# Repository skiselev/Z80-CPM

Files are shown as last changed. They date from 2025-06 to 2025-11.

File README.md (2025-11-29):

# Z80-CPM
RCBus Z80 CPU, 512 KiB SRAM, and 512 KiB Flash ROM module for RCBus systems designed using discrete logic

## Table of Content
* [Overview](#overview)
  * [Specifications](#specifications)
* [Assembly Instructions](#assembly-instructions)
* [Hardware Documentation](#hardware-documentation)
  * [Schematic and PCB Layout](#schematic-and-pcb-layout)
  * [Input/Output Ports](#inputoutput-ports)
  * [Connectors](#connectors)
  * [Bill of Materials](#bill-of-materials)
* [Release Notes](#release-notes)
  * [Changes](#changes)
  * [Known Issues](#known-issues)
* [Red Tape](#red-tape)
  * [Licensing](#licensing)
  * [Trademarks](#trademarks)

## Overview
Z80-CPM is an RCBus and RC2014* compatible module, designed to run [RomWBW](https://github.com/wwarthen/RomWBW) firmware including CP/M, ZSDOS, and various applications under these OSes. Z80-CPM combines functionality of the following RC2014* modules on a single module, thus saving space on the backplane:
* Z80 CPU Module
* 512k ROM 512k RAM Module - Simplified version, compatible with RomWBW firmware
* Clock and Reset Module

Minimal CP/M computer system can be built using Z80-CPM module, a backplane, and a serial port module, for example Steve Cousins' [SC716](https://smallcomputercentral.com/sc716-rcbus-z80-sio-2-serial-module/) or [SC725](https://smallcomputercentral.com/sc725-rcbus-serial-and-timer-module/) Z80 SIO modules, or MC68B50 ACIA. A Compact Flash module can be added for additional storage. For a compact system, a 3-slot [SC723](https://smallcomputercentral.com/sc723-rcbus-backplane-3/) can be used.

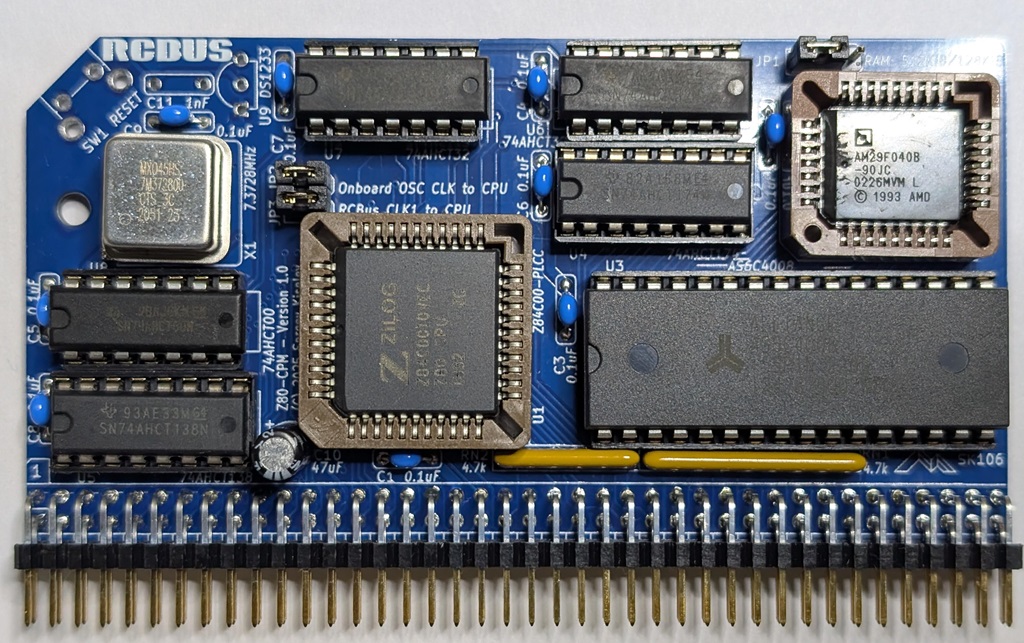
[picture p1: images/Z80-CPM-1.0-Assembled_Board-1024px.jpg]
Z80-CPM Assembled Board


### Specifications
* Processor: Zilog* Z80 CPU (CMOS version - Z84C00)
* Memory: 512 KiB SRAM, 512 KiB Flash ROM, RomWBW compatible memory pager
* Bus: RCBus, RC2014* compatible
* Microprocessor Supervisor for system reset generation

## Assembly Instructions

Please refer to [Assembly Instructions](Assembly_Instructions.md) document

## Hardware Documentation

### Schematic and PCB Layout

* [Schematic - Version 1.0](KiCad/Z80-CPM-Schematic-1.0.pdf)
* [PCB Layout - Version 1.1](KiCad/Z80-CPM-Board-1.1.pdf)
* [PCB Layout - Version 1.0](KiCad/Z80-CPM-Board-1.0.pdf)

### Memory Configuration Input/Output Ports
Z80-CPM supports up to 512 KiB of RAM and up to 512 KiB of Flash ROM. It has a simple memory bank switching mechanism with two 32 KiB memory banks, inspired by Steve Cousin's [SC602](https://smallcomputercentral.com/rcbus/sc600-series/sc602-rcbus-z80-memory-module/) Memory Module. This memory bank mechanism provides minimal required functionality for the RomWBW RCZ80_std.rom image to be used without any modifications.
The upper 32 KiB bank is always mapped to the top 32 KiB of the physical RAM. The lower 32 KiB bank can be mapped to any 32 KiB size page in the physical memory. The memory page is selected by writting either 0x78 or 0x79 I/O ports, that are mapped to the same page select register.

#### 0x78 or 0x79 - Memory Page Select Register (Write-only)

Port       | Bit # | Function                               | Value
-----------|-------|----------------------------------------|-----------------------
0x78, 0x79 | 0     | Not implemented                        | Can be set to either 0 or 1
0x78, 0x79 | 5-1   | Page number for bank #0 0x0000-0xr7FFF | 0-31 - Page number
0x78, 0x79 | 7-6   | Not implemented                        | Should be set to 0

* Notes:
  * The register is reset to '0' on power-on or reset, which maps the lower 32 KiB of the Flash ROM to bank #0.
  * Bit 5 selects between the Flash ROM (bit 5 = 0) and the RAM (bit 5 = 1).

### Jumpers Settings

#### JP1 - RAM Size Configuration

Jumper Position | Description
----------------|------------
1-2             | 512 KiB SRAM
2-3             | 128 KiB SRAM

#### JP2 - Connect on-board oscillator clock to the CPU

Jumper Position | Description
----------------|------------
**Closed**      | X1 oscillator is connected to the CPU
Open            | X1 oscillator is not connected to the CPU

#### JP3 - Connect the RCBus CLK1 signal to the CPU

Jumper Position | Description
----------------|------------
**Closed**      | CLK1 signal is connected to the CPU
Open            | CLK1 signal is not connected to the CPU

#### JP2 and JP3 Configuration Notes

The module supports the following options for the CPU clock:
1. **Default**: CPU uses the clock frequency generated by the X1 oscillator, and the X1 clock frequency is output to CLK1 signal on RCBus. Install both JP2 and JP3 for this option.
2. CPU uses the clock frequency provided by another module on RCBus. Install only JP3 for this option.
3. CPU uses the clock frequency generated by the X1 oscillator, while other modules use different CLK1 signal. This might be useful, for example, when running the CPU on a frequency other than 7.3728 MHz. Install only JP2 for this option.

### Connectors

#### J1 - RC2014* Bus
Pin | Signal Name | Description                             | Pin | Signal Name | Description
--- | ----------- | --------------------------------------- | --- | ----------- | -----------
1   | A15         | Address A15; Output                    | 41  | p41         | Reserved; Not connected
2   | A14         | Address A14; Output                     | 42  | /BAI        | Bus Acknowledge In; Not connected
3   | A13         | Address A13; Output                     | 43  | /BAO        | Bus Acknowledge Out; Not connected
4   | A12         | Address A12; Output                     | 44  | p44         | Reserved; Not connected
5   | A11         | Address A11; Output                     | 45  | p45         | Reserved; Not connected
6   | A10         | Address A10; Output                     | 46  | p46         | Reserved; Not connected
7   | A9          | Address A9; Output                      | 47  | p47         | Reserved; Not connected
8   | A8          | Address A8; Output                      | 48  | p48         | Reserved; Not connected
9   | A7          | Address A7; Output                      | 49  | A23         | Address A23; Not connected
10  | A6          | Address A6; Output                      | 50  | A22         | Address A22; Not connected
11  | A5          | Address A5; Output                      | 51  | A21         | Address A21; Not connected
12  | A4          | Address A4; Output                      | 52  | A20         | Address A20; Not connected
13  | A3          | Address A3; Output                      | 53  | A19         | Address A19; Output
14  | A2          | Address A2; Output                      | 54  | A18         | Address A18; Output
15  | A1          | Address A1; Output                      | 55  | A17         | Address A17; Output
16  | A0          | Address A0; Output                      | 56  | A16         | Address A16; Output
17  | GND         | Ground                                  | 57  | GND         | Ground
18  | VCC         | Power Supply - +5V                      | 58  | VCC         | Power Supply - +5V
19  | /M1         | Machine Cycle One; Output               | 59  | /RFSH       | DRAM refresh; Output
20  | /RESET      | Reset; Output                           | 60  | PAGE         | Page ROM/RAM input; Not connected
21  | CLK1        | CPU Clock; Output                       | 61  | CLK2        | UART Clock; Not connected
22  | /INT        | Interrupt; Input                        | 62  | /BUSACK     | DMA Bus Acknowledge; Output
23  | /MREQ       | Memory Request; Output                  | 63  | /HALT       | Halt; Output
24  | /WR         | Write Request; Output                   | 64  | /BUSREQ     | DMA Bus Request; Input
25  | /RD         | Read Request; Output                    | 65  | /WAIT       | Wait; Input
26  | /IORQ       | Input/Output Request; Output            | 66  | /NMI        | Non-maskable Interrupt; Input
27  | D0          | Data D0; Input/Output                   | 67  | D8          | Data D8; Input/Output; Not connected
28  | D1          | Data D1; Input/Output                   | 68  | D9          | Data D9; Input/Output; Not connected
29  | D2          | Data D2; Input/Output                   | 69  | D10         | Data D10; Input/Output; Not connected
30  | D3          | Data D3; Input/Output                   | 70  | D11         | Data D11; Input/Output; Not connected
31  | D4          | Data D4; Input/Output                   | 71  | D12         | Data D12; Input/Output; Not connected
32  | D5          | Data D5; Input/Output                   | 72  | D13         | Data D13; Input/Output; Not connected
33  | D6          | Data D6; Input/Output                   | 73  | D14         | Data D14; Input/Output; Not connected
34  | D7          | Data D7; Input/Output                   | 74  | D15         | Data D15; Input/Output; Not connected
35  | TX          | Channel 1, Transmit Data; Not Connected | 75  | TX2         | Channel 2, Transmit Data; Not Connected
36  | RX          | Channel 1, Receive Data; Not Connected  | 76  | RX2         | Channel 2, Receive Data; Not Connected
37  | /IRQ1       | Interrupt Request 1; Not connected      | 77  | /IRQ2       | Interrupt Request 2; Not connected
38  | IEI         | Interrupt Enable In; Not connected      | 78  | p78         | Reserved; Not connected
39  | IEO         | Interrupt Enable Out; Not connected     | 79  | p79         | Reserved; Not connected
40  | USER4       | User Pin 4; Not connected               | 80  | USER8       | User Pin 8; Not connected

### Bill of Materials

#### Version 1.0

Mouser projects - All components except of the PCB and the CPU:
* [Z80-CPM project](https://www.mouser.com/Tools/Project/Share?AccessID=cf00dde769)
  * Note that optional CPU supervisor parts: U9 DS1233 CPU supervisor, C11 1 nF capacitor, and SW1 tactile switch are included in this project.

Z80-CPM project on Tindie:
* [Complete kit](https://www.tindie.com/products/weird/z80-cpm-rcbus-module-kit/).
* [Z80-CPU PCB](https://www.tindie.com/products/weird/z80-cpm-rcbus-module-pcb/).

Component type     | Reference | Description                                 | Quantity | Possible sources and notes 
------------------ | --------- | ------------------------------------------- | -------- | --------------------------
PCB                |           | Z80-CPM PCB - Version 1.0                   | 1        | Buy from my Tindie store: [Complete kit](https://www.tindie.com/products/weird/z80-cpm-rcbus-module-kit/); [Z80-CPM PCB](https://www.tindie.com/products/weird/z80-cpm-rcbus-module-pcb/), or order from a PCB manufacturer of your choice using provided Gerber or KiCad files
Integrated Circuit | U1        | Z84C00xxVEG - Z80 CPU, CMOS, 44 pin PLCC    | 1        | Mouser [692-Z84C0010VEG](https://www.mouser.com/ProductDetail/692-Z84C0010VEG)
Integrated Circuit | U2        | SST39SF040 - 512 KiB Flash ROM, 32 pin PLCC | 1        | Mouser [804-39SF0407CNHE](https://www.mouser.com/ProductDetail/804-39SF0407CNHE)
Integrated Circuit | U3        | AS6C4008 - 512 KiB SRAM, 32 pin DIP         | 1        | Mouser [913-AS6C4008-55PCN](https://www.mouser.com/ProductDetail/913-AS6C4008-55PCN)
Integrated Circuit | U4        | 74AHCT174 - Hex D-Type Flip Flop, 16 pin DIP | 1       | Mouser [595-SN74AHCT174N](https://www.mouser.com/ProductDetail/595-SN74AHCT174N)
Integrated Circuit | U5        | 74HCT138 - 3-to-8 Decoder, 16 pin DIP       | 1        | Mouser [595-CD74HCT138E](https://www.mouser.com/ProductDetail/595-CD74HCT138E)
Integrated Circuit | U6, U7    | 74AHCT32 - Quad 2-Input OR Gate, 14 pin DIP | 2        | Mouser [595-SN74AHCT32N](https://www.mouser.com/ProductDetail/595-SN74AHCT32N)
Integrated Circuit | U8        | 74AHCT00 - Quad 2-Input NAND Gate, 14 pin DIP | 1      | Mouser [595-SN74AHCT00N](https://www.mouser.com/ProductDetail/595-SN74AHCT00N)
Integrated Circuit | U9        | DS1233-5 - CPU Supervisor, 5V, TO-92-3      | 1        | Mouser [700-DS1233-5](https://www.mouser.com/ProductDetail/700-DS1233-5). Note U9 is an optional on-board CPU supervisor.
Oscillator         | X1        | 7.3728 MHz, CMOS oscillator, half can       | 1        | Mouser [774-MXO45HS-3C-7.3](https://www.mouser.com/ProductDetail/774-MXO45HS-3C-7.3) or [520-2200B-073](https://www.mouser.com/ProductDetail/520-2200B-073)
Pin Header         | J1        | 40x2 pin header, 2.54 mm pitch, right angle | 1        | Mouser [737-PH2RA-80-UA](https://www.mouser.com/ProductDetail/737-PH2RA-80-UA), [517-5121TG](https://www.mouser.com/ProductDetail/517-5121TG)
Pin Header         | JP1       | 3x1 pin header, 2.54 mm pitch, vertical     | 1        | Mouser [649-68000-203HLF](https://www.mouser.com/ProductDetail/649-68000-203HLF).
Pin Header         | JP2, JP3  | 2x2 pin header, 2.54 mm pitch, vertical     | 1        | Mouser [649-67996-104HLF](https://www.mouser.com/ProductDetail/649-67996-104HLF).
Jumper             | JP1 - JP3 | Shunt, 2 pin 2.54 mm pitch                  | 3        | Mouser [806-SX1100-B](https://www.mouser.com/ProductDetail/806-SX1100-B).
Tactile switch     | SW1       | Tactile switch, 6 mm, right angle           | 1        | Mouser [653-B3F-3152](https://www.mouser.com/ProductDetail/653-B3F-3152). SW1 is an optional reset switch.
Capacitor          | C1 - C9   | 0.1 uF, 50V, MLCC, 5 mm pitch               | 9        | Mouser [594-K104K15X7RF53H5](https://www.mouser.com/ProductDetail/594-K104K15X7RF53H5).
Capacitor          | C10        | 47 uF, 25V, electrolytic, 5 x 11 mm, 2 mm pitch | 1    | Mouser [667-EEU-FR1E470](https://www.mouser.com/ProductDetail/667-EEU-FR1E470)
Capacitor          | C11       | 1 nF, 50V, MLCC, 5 mm pitch                 | 1        | Mouser [594-K102K15X7RF5TH5](https://www.mouser.com/ProductDetail/594-K102K15X7RF5TH5). Note: C11 is optional, required if U9 installed and manual reset functionality is desired.
Resistor Array     | RN1       | 4.7 kohm, bussed, 9 pin SIP                 | 1        | Mouser [652-4609X-1LF-4.7K](https://www.mouser.com/ProductDetail/652-4609X-1LF-4.7K) or [652-4609X-AP1-472LF](https://www.mouser.com/ProductDetail/652-4609X-AP1-472LF)
Resistor Array     | RN2       | 4.7 kohm, bussed, 6 pin SIP                 | 1        | Mouser [652-4606X-1LF-4.7K](https://www.mouser.com/ProductDetail/652-4606X-1LF-4.7K) or [652-4606X-AP1-472LF](https://www.mouser.com/ProductDetail/652-4606X-AP1-472LF)
IC Socket          | U1        | 44 pin PLCC, through hole                   | 1        | Mouser [737-PLCC-44-AT](https://www.mouser.com/ProductDetail/737-PLCC-44-AT), [517-8444-11B1-RK-TP](https://www.mouser.com/ProductDetail/517-8444-11B1-RK-TP)
IC Socket          | U2        | 32 pin PLCC, through hole                   | 1        | Mouser [737-PLCC-32-AT](https://www.mouser.com/ProductDetail/737-PLCC-32-AT), [517-8432-11B1-RK-TP](https://www.mouser.com/ProductDetail/517-8432-11B1-RK-TP)
IC Socket          | U3        | 32 pin DIP                                  | 1        | Mouser [737-ICS-632-T](https://www.mouser.com/ProductDetail/737-ICS-632-T), [517-4832-6000-CP](https://www.mouser.com/ProductDetail/517-4832-6000-CP)
IC Socket          | U4, U5    | 16 pin DIP                                  | 2        | Mouser [737-ICS-316-T](https://www.mouser.com/ProductDetail/737-ICS-316-T), [517-4816-3000-CP](https://www.mouser.com/ProductDetail/517-4816-3000-CP).
IC Socket          | U6 - U8   | 14 pin DIP                                  | 3        | Mouser [737-ICS-314-T](https://www.mouser.com/ProductDetail/737-ICS-314-T), [517-4816-3000-CP](https://www.mouser.com/ProductDetail/517-4816-3000-CP).
Oscillator Socket  | X1        | 4 pin DIP, Half Can                         | 1        | Mouser [535-1108800](https://www.mouser.com/ProductDetail/535-1108800)

## Release Notes

### Changes

* Version 1.1
  * Fix cosmetic issues:
    * Swap C5 with C8 and C4 with C6.
    * Modify C10 footpring to clearly show negative terminal.

* Version 1.0
  * Initial version.

### Known Issues

* Version 1.0
  * Cosmetic issues:
    * C5 and C8, and C6 and C4 should be swapped.
    * C10 should have more clear marking for the negative terminal.

## Red Tape

### Licensing

Z80-CPM is an open source hardware project. The hardware design itself, including schematic and PCB layout design files are licensed under the strongly-reciprocal variant of [CERN Open Hardware Licence version 2](license-cern_ohl_s_v2.txt). Documentation, including this file, is licensed under the [Creative Commons Attribution-ShareAlike 4.0 International License](license-cc-by-sa-4.0.txt).

CERN-OHL-2.0-S, GPL-3.0, CC-BY-SA-4.0

### Trademarks

* "RC2014" is a registered trademark of RFC2795 Ltd.
* Other names and brands may be claimed as the property of others.

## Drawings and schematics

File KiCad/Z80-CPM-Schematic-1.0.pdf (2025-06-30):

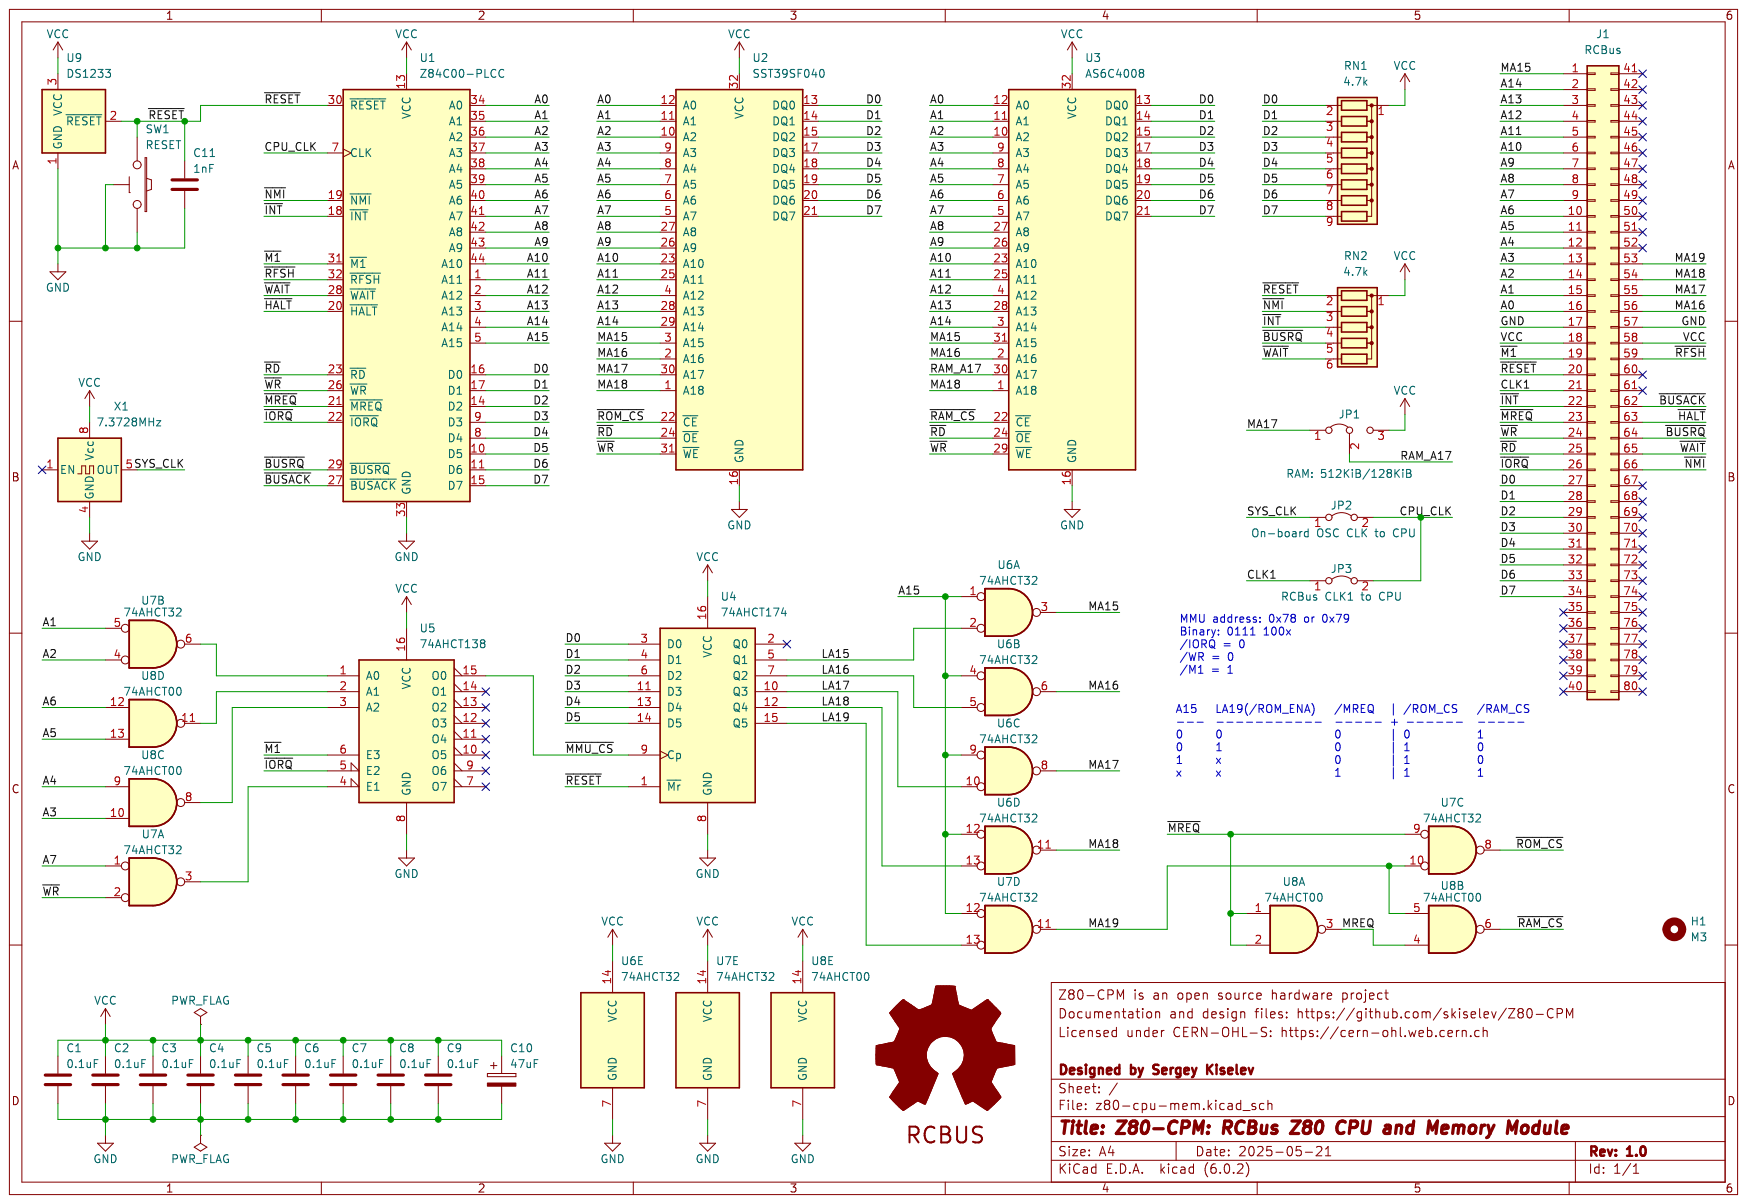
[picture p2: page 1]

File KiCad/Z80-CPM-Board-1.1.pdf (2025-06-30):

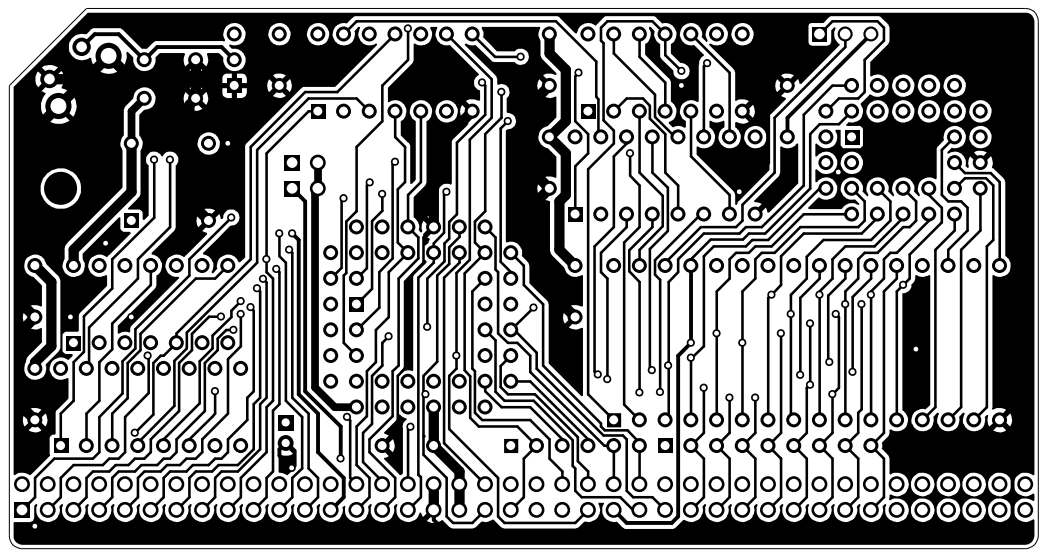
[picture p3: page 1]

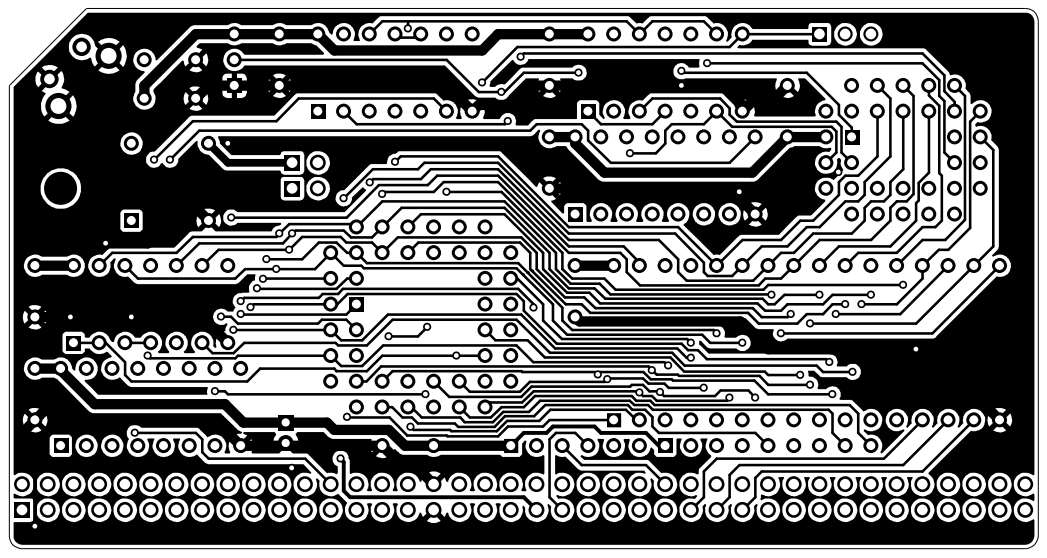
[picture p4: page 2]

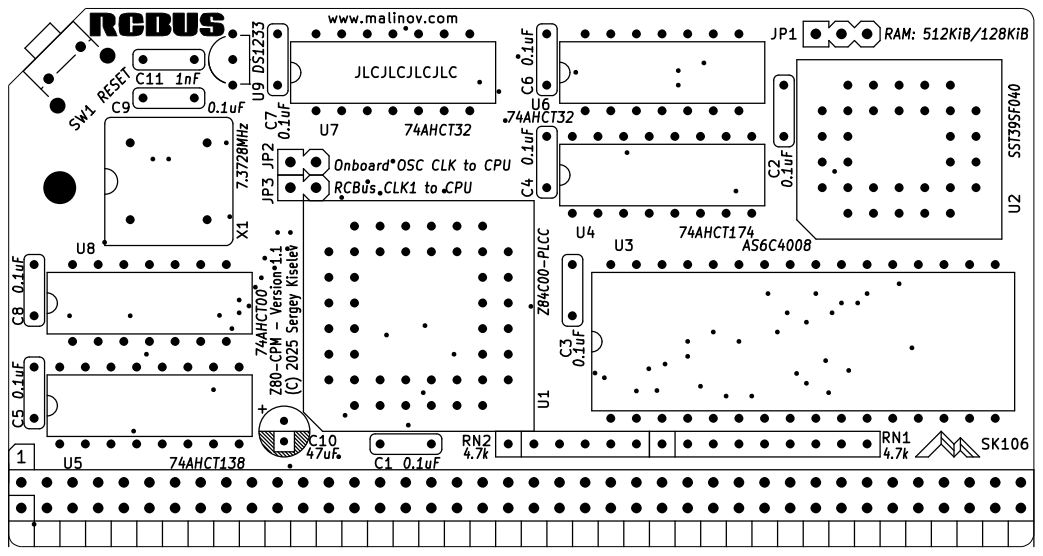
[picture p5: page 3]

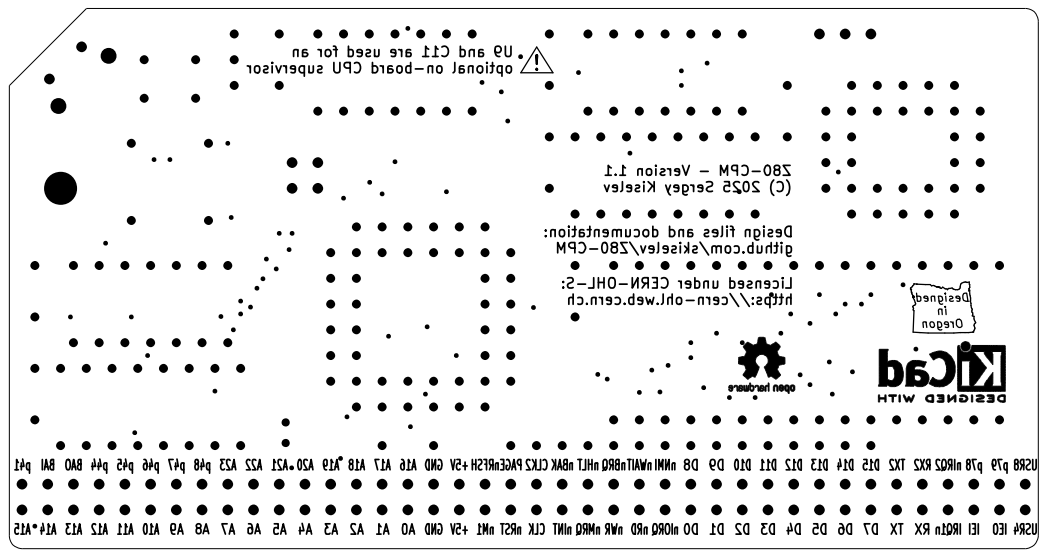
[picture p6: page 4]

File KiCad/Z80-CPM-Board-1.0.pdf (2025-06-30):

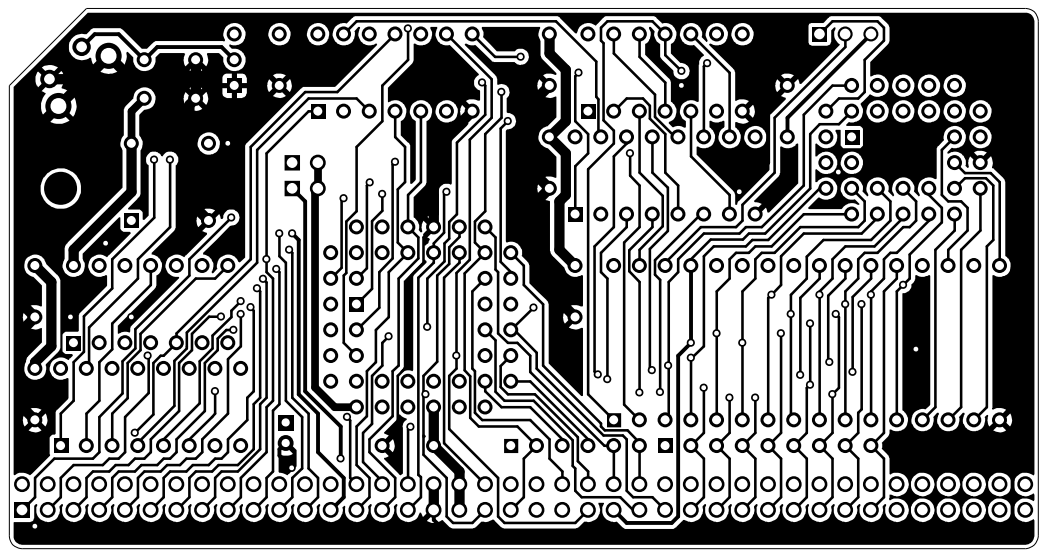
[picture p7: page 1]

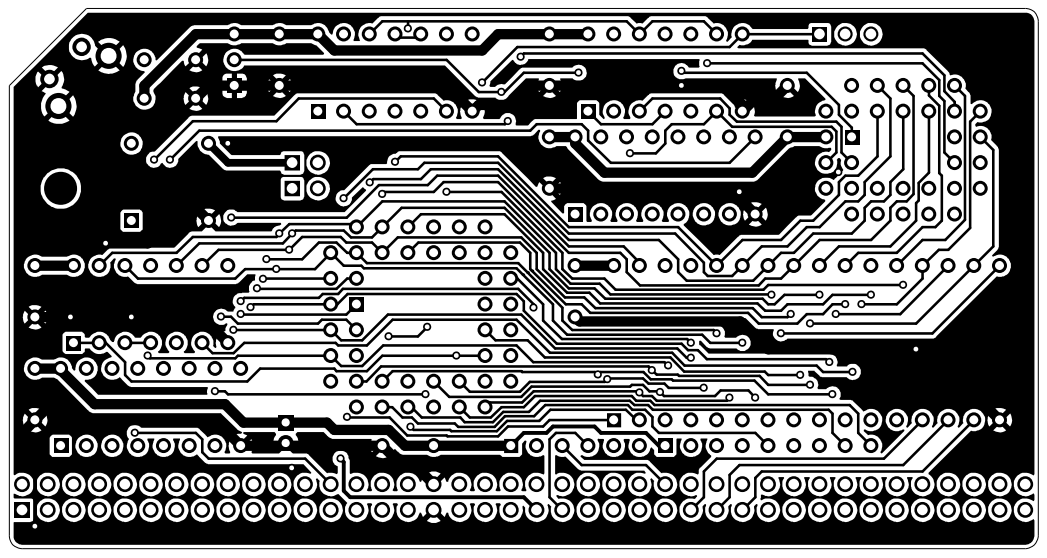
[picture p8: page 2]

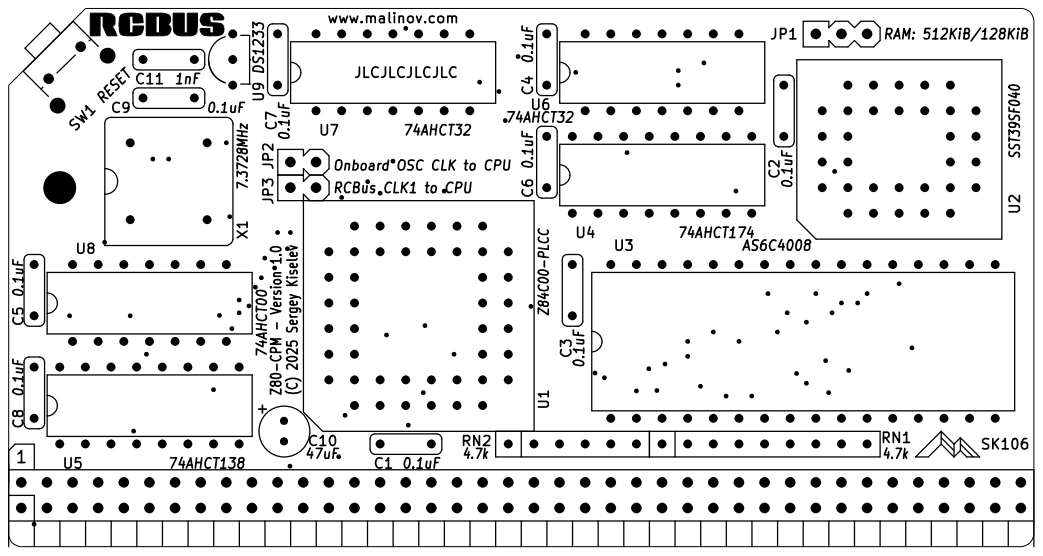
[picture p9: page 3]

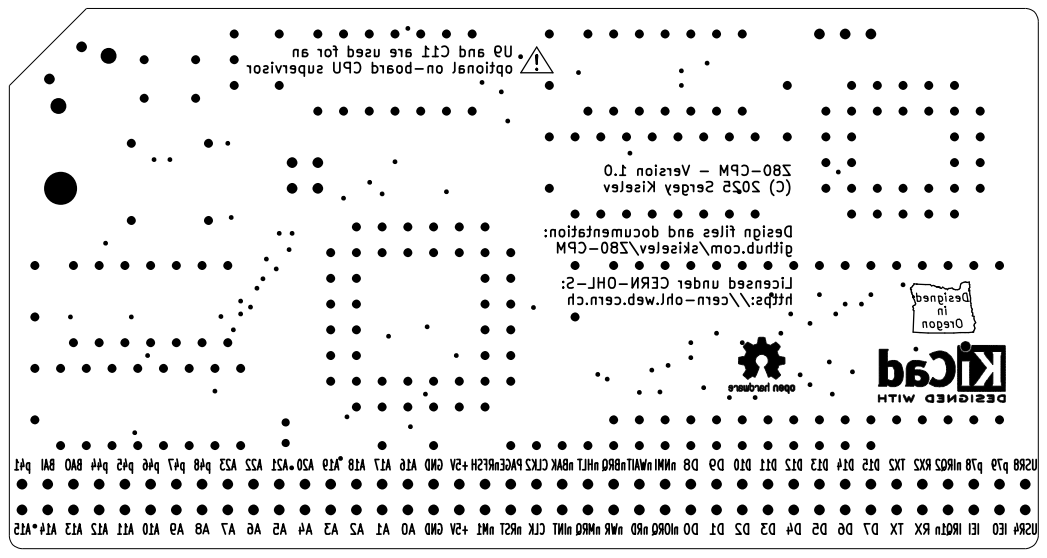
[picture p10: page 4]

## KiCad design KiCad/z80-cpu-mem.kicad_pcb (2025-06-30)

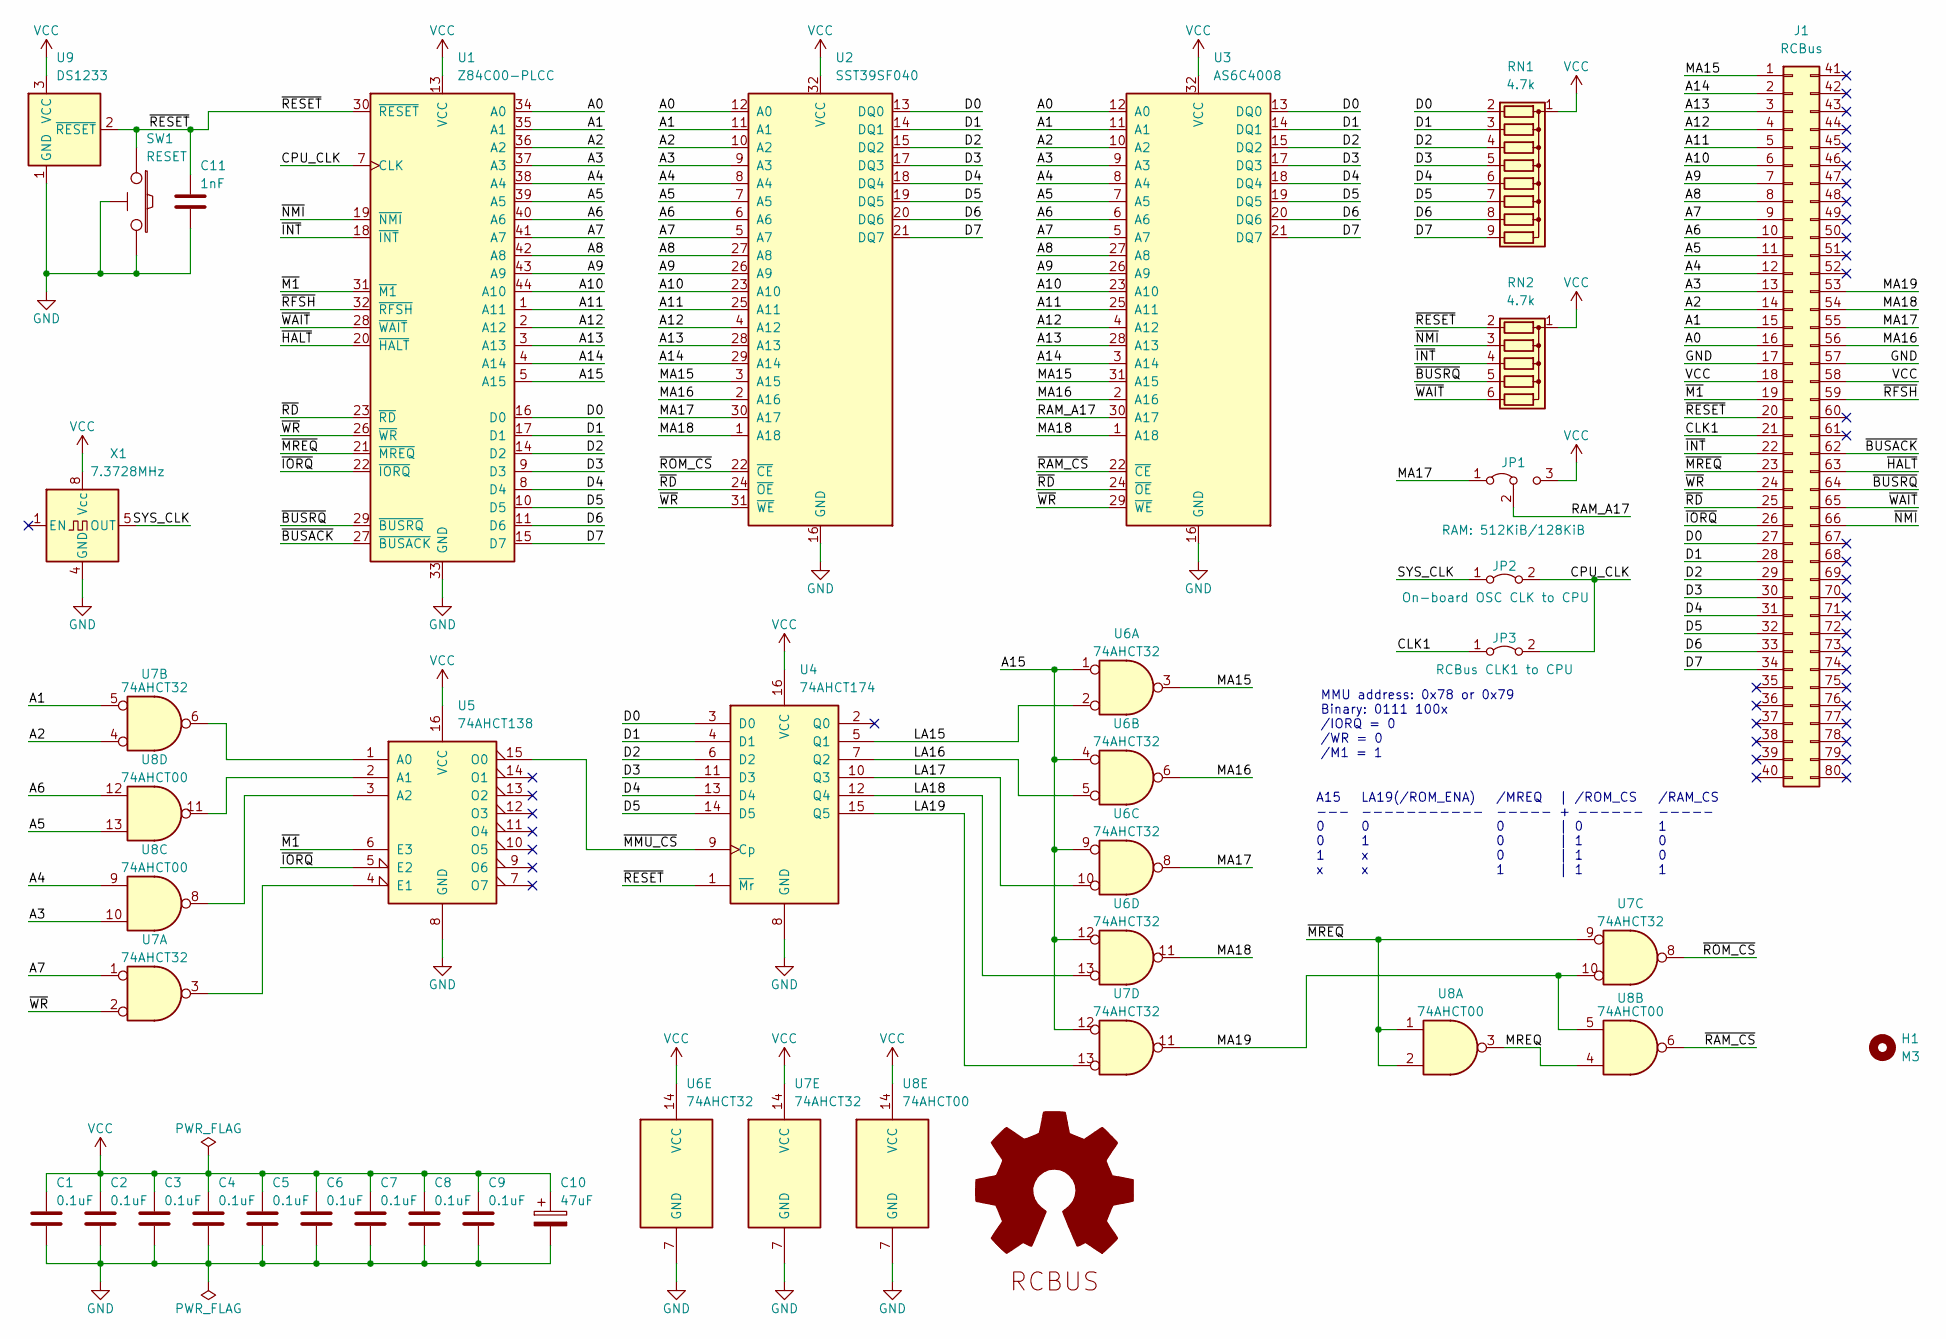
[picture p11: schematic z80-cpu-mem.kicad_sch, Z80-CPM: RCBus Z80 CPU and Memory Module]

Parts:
C1, C2, C3, C4, C5, C6, C7, C8, C9: 0.1uF; Cap_Cer_508
C10: 47uF; Cap_Elec_Radial_5mm
C11: 1nF; Cap_Cer_508
H1: M3; MountingHole_3.2mm_M3_DIN965
J1: RCBus; Conn_Pin_Header_40x2_2.54mm_Right_Angle_RCBus80
JP1: RAM: 512KiB/128KiB; Conn_Pin_Header_3x1_2.54mm
JP2: On-board OSC CLK to CPU; Conn_Pin_Header_2x1_2.54mm
JP3: RCBus CLK1 to CPU; Conn_Pin_Header_2x1_2.54mm
LOGO1: Logo_Open_Hardware_Large; OSHW-Logo2_7.3x6mm_SilkScreen
LOGO2: RCBUS_Logo
RN1: 4.7k; Conn_SIL9
RN2: 4.7k; Conn_SIL6
SW1: RESET; Switch_Tactile_6mm_Right
U1: Z84C00-PLCC; IC_PLCC44_TH
U2: SST39SF040; IC_PLCC32_TH
U3: AS6C4008; IC_DIP32_600
U4: 74AHCT174; IC_DIP16_300
U5: 74AHCT138; IC_DIP16_300
U6, U7: 74AHCT32; IC_DIP14_300
U8: 74AHCT00; IC_DIP14_300
U9: DS1233; Transistor_TO92_EBC_254
X1: 7.3728MHz; OSC_Half_Can_DIP8

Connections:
/A0: J1.16, U1.34 (A0), U2.12 (A0), U3.12 (A0)
/A1: J1.15, U1.35 (A1), U2.11 (A1), U3.11 (A1), U7.5
/A2: J1.14, U1.36 (A2), U2.10 (A2), U3.10 (A2), U7.4
/A3: J1.13, U1.37 (A3), U2.9 (A3), U3.9 (A3), U8.10
/A4: J1.12, U1.38 (A4), U2.8 (A4), U3.8 (A4), U8.9
/A5: J1.11, U1.39 (A5), U2.7 (A5), U3.7 (A5), U8.13
/A6: J1.10, U1.40 (A6), U2.6 (A6), U3.6 (A6), U8.12
/A7: J1.9, U1.41 (A7), U2.5 (A7), U3.5 (A7), U7.1
/A8: J1.8, U1.42 (A8), U2.27 (A8), U3.27 (A8)
/A9: J1.7, U1.43 (A9), U2.26 (A9), U3.26 (A9)
/A10: J1.6, U1.44 (A10), U2.23 (A10), U3.23 (A10)
/A11: J1.5, U1.1 (A11), U2.25 (A11), U3.25 (A11)
/A12: J1.4, U1.2 (A12), U2.4 (A12), U3.4 (A12)
/A13: J1.3, U1.3 (A13), U2.28 (A13), U3.28 (A13)
/A14: J1.2, U1.4 (A14), U2.29 (A14), U3.3 (A14)
/A15: U1.5 (A15), U6.1, U6.4, U6.9, U6.12, U7.12
/CLK1: J1.21, JP3.1 (A)
/CPU_CLK: JP2.2 (B), JP3.2 (B), U1.7 (CLK)
/D0: J1.27, RN1.2 (R1), U1.16 (D0), U2.13 (DQ0), U3.13 (DQ0), U4.3 (D0)
/D1: J1.28, RN1.3 (R2), U1.17 (D1), U2.14 (DQ1), U3.14 (DQ1), U4.4 (D1)
/D2: J1.29, RN1.4 (R3), U1.14 (D2), U2.15 (DQ2), U3.15 (DQ2), U4.6 (D2)
/D3: J1.30, RN1.5 (R4), U1.9 (D3), U2.17 (DQ3), U3.17 (DQ3), U4.11 (D3)
/D4: J1.31, RN1.6 (R5), U1.8 (D4), U2.18 (DQ4), U3.18 (DQ4), U4.13 (D4)
/D5: J1.32, RN1.7 (R6), U1.10 (D5), U2.19 (DQ5), U3.19 (DQ5), U4.14 (D5)
/D6: J1.33, RN1.8 (R7), U1.11 (D6), U2.20 (DQ6), U3.20 (DQ6)
/D7: J1.34, RN1.9 (R8), U1.15 (D7), U2.21 (DQ7), U3.21 (DQ7)
/LA15: U4.5 (Q1), U6.2
/LA16: U4.7 (Q2), U6.5
/LA17: U4.10 (Q3), U6.10
/LA18: U4.12 (Q4), U6.13
/LA19: U4.15 (Q5), U7.13
/MA15: J1.1, U2.3 (A15), U3.31 (A15), U6.3
/MA16: J1.56, U2.2 (A16), U3.2 (A16), U6.6
/MA17: J1.55, JP1.1 (A), U2.30 (A17), U6.8
/MA18: J1.54, U2.1 (A18), U3.1 (A18), U6.11
/MA19: J1.53, U7.10, U7.11, U8.5
/MREQ: U8.3, U8.4
/RAM_A17: JP1.2 (C), U3.30 (A17)
/SYS_CLK: JP2.1 (A), X1.5 (OUT)
/~BUSACK: J1.62, U1.27 (~BUSACK)
/~BUSRQ: J1.64, RN2.5 (R4), U1.29 (~BUSRQ)
/~HALT: J1.63, U1.20 (~HALT)
/~INT: J1.22, RN2.4 (R3), U1.18 (~INT)
/~IORQ: J1.26, U1.22 (~IORQ), U5.5 (E2)
/~M1: J1.19, U1.31 (~M1), U5.6 (E3)
/~MMU_CS: U4.9 (Cp), U5.15 (O0)
/~MREQ: J1.23, U1.21 (~MREQ), U7.9, U8.1, U8.2
/~NMI: J1.66, RN2.3 (R2), U1.19 (~NMI)
/~RAM_CS: U3.22 (~CE), U8.6
/~RD: J1.25, U1.23 (~RD), U2.24 (~OE), U3.24 (~OE)
/~RESET: C11.1, J1.20, RN2.2 (R1), SW1.1, U1.30 (~RESET), U4.1 (~Mr), U9.2 (~RESET)
/~RFSH: J1.59, U1.32 (~RFSH)
/~ROM_CS: U2.22 (~CE), U7.8
/~WAIT: J1.65, RN2.6 (R5), U1.28 (~WAIT)
/~WR: J1.24, U1.26 (~WR), U2.31 (~WE), U3.29 (~WE), U7.2
GND: C1.2, C2.2, C3.2, C4.2, C5.2, C6.2, C7.2, C8.2, C9.2, C10.2, C11.2, J1.17, J1.57, SW1.2, SW1.GND, U1.33 (GND), U2.16 (GND), U3.16 (GND), U4.8 (GND), U5.8 (GND), U6.7 (GND), U7.7 (GND), U8.7 (GND), U9.1 (GND), X1.4 (GND)
unnamed: U5.1 (A0), U7.6
unnamed: U5.2 (A1), U8.11
unnamed: U5.3 (A2), U8.8
unnamed: U5.4 (E1), U7.3
VCC: C1.1, C2.1, C3.1, C4.1, C5.1, C6.1, C7.1, C8.1, C9.1, C10.1, J1.18, J1.58, JP1.3 (B), RN1.1 (common), RN2.1 (common), U1.13 (VCC), U2.32 (VCC), U3.32 (VCC), U4.16 (VCC), U5.16 (VCC), U6.14 (VCC), U7.14 (VCC), U8.14 (VCC), U9.3 (VCC), X1.8 (Vcc)

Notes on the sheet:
/RAM_CS ----- 1 0 0 1
LA19(/ROM_ENA) ----------- 0 1 x x
MMU address: 0x78 or 0x79 Binary: 0111 100x /IORQ = 0 /WR = 0 /M1 = 1
/MREQ ----- 0 0 0 1
A15 --- 0 0 1 x
| /ROM_CS + ------ | 0 | 1 | 1 | 1

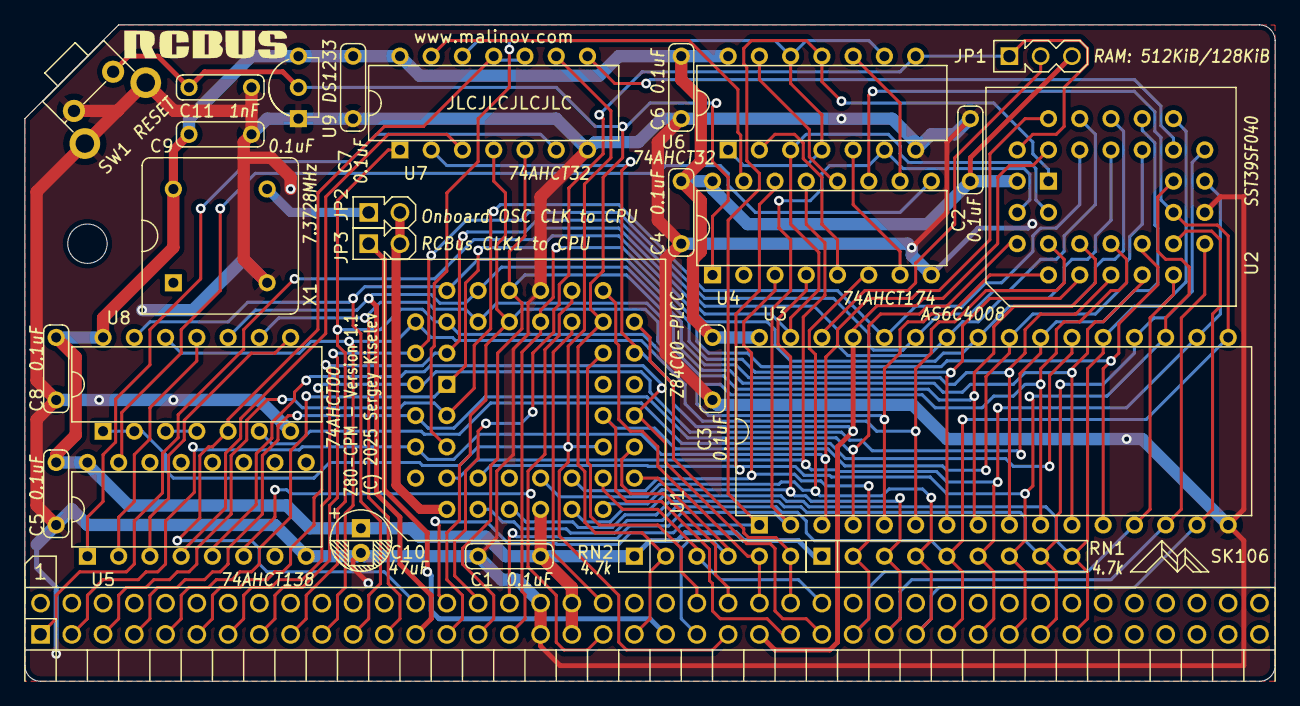
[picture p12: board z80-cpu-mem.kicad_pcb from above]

Board: 2 copper layers, 101.6 x 53.3 mm, 31 parts (1 on the bottom side), 61 nets.

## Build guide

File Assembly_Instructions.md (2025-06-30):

# Z80-CPM - Assembly Instructions

## Prerequisites

### Tools, Equipment, and Supplies

* Soldering iron with a fine tip. Temperature controlled soldering station is recommended
* Needle nose pliers for forming components' leads
* Small side cutters for cutting components' leads
* Universal programmer capable of programming SST39F040 Flash ROM ICs. For example, MiniPro TL866CS or MiniPro TL866A
* Multimeter with frequency measurement, an oscilloscope, or a logic analyzer can be beneficial for troubleshooting
* Desk lamp, magnifying glass
* Solder suitable for soldering electronics. For example: rosin core Sn63/Pb37, Sn60/Pb40, or a lead-free solder such as Sn96.5/Ag3.0/Cu0.5 (sometimes referred to as SAC305)
* Solder wick for removing excess of solder
* 99% Isopropyl Alcohol for removing the excess of flux after soldering
* Lint free wipes, used toothbrush, cotton swabs for cleaning the PCB before and after soldering

### Parts

The table below shows the images of the components included in the kit. The up to date list of parts provided in the [Bill of Materials](README.md#bill-of-materials) section of the [README.md](README.md) file. It also provides the recommended sources for the parts.

#### TODO: Update the table

## Assembly Steps

### 1. Gather supplies and parts

* Check that you have all the equipment and parts listed in the [Prerequisites](#prerequisites) section above
* Organize your workspace. If available, use ESD-safe surface and ESD strap when working on this project

### 2. Solder the components

#### TODO: Update detailed instructions

Solder the components going from lower profile components to higher profile components, from smaller components to larger. Here is the recommended order:

* Solder RN1 and RN2 resistor arrays. Make sure that resistor arrays are oriented correctly. The first pin of the resistor array is marked with a printed dot, and the first pad on the board has a square shape

* Solder C1-C9 0.1 uF capacitors. Note that these are non-polarized ceramic capacitors, so they can be oriented either way. Trim the leads using cutters

* Solder the sockets. Start with the X1 oscillator socket, continue with DIP integrated circuits' sockets, and finally solder PLCC44 and PLCC32 sockets.
  * Pay attention to the orientation of the sockets. The indents indicating pin 1, or the socket outline on the PCB's silk screen should match the socket orientation

* Solder C10 capacitor. Note that this is a __polarized__ electrolytic capacitor and it needs to be oriented properly. Make sure that the negative lead of the capacitor (marked on the package) matches the white colored area on the PCB.

* Solder RCBus header J1
  
### 3. Check your soldering work

* Make sure all pins of all components are soldered properly
* If desired, clean the flux using isopropyl alcohol, cotton swabs. You might want to scrub the board lightly with a used toothbrush to remove the flux

### 4. Insert the integrated circuits to the sockets
* Prior to inserting DIP integrated circuits to the sockets board, bend their leads slightly, so they point 90 degrees downward. Put the IC on the side and gently push it down to bend the leads. Repeat on the other side of the IC
* Double check that you're placing the integrated circuit in the right socket, check the IC orientation. The index notch on the IC should match the notch on the socket and the drawing on the PCB's silkscreen
* To insert the Z80 CPU and SST39SF040 Flash ROM integrated circuits in PLCC packages, place them on the top of their sockets, double check the orientation of the integrated circuit, and firmly push it down. It should click into the socket

Assembled board

### 5. Install JP1, JP2, and JP3 jumpers

Refer to the [Jumpers Settings](README.md#jumpers-settings) section of the [README.md](README.md) file.

### 6. Test the module
* Plug the module into an RCBus compatible backplane
* Plug a supported serial module, such as Steve Cousins' [[SC716 – RCBus Z80 SIO/2 Serial Module](https://smallcomputercentral.com/sc716-rcbus-z80-sio-2-serial-module/), [SC725 – RCBus Serial and Timer Module](https://smallcomputercentral.com/sc725-rcbus-serial-and-timer-module/), or [SC705 – RCBus Serial ACIA Module](https://smallcomputercentral.com/sc705-rcbus-serial-acia/).
* Double check that the modules are installed in the correct orientation, and pin 1 on the modules match that of the backplane.
* Connect the serial console cable, such as FTDI USB to RS232 to the serial module. Launch terminal emulation software, and configure it for 115200bps, 8-bit, no parity, one stop bit operation.
* Apply the power. The RomWBW prompt should appear on the terminal.

__Congratulations! Enjoy your Z80-CPM Module!__

A CP/M computer system consisting of [Z80-CPM module](https://github.com/skiselev/Z80-CPM), [Flock V2 Floppy Disk Controller and Real Time Clock module](https://github.com/skiselev/flock-v2), [SC725 – RCBus Serial and Timer Module](https://smallcomputercentral.com/sc725-rcbus-serial-and-timer-module/), and [SC701 – RCBUS Backplane](https://smallcomputercentral.com/sc701-rcbus-backplane/):

#### TODO: Add a photo of a complete system

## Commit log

2025-06-30 Add v1.0 files
    [z80-cpu-mem-B_Cu.gbr, z80-cpu-mem-B_Mask.gbr, z80-cpu-mem-B_Silkscreen.gbr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]
2025-06-30 Add files for v1.1
    [z80-cpu-mem-B_Cu.gbr, z80-cpu-mem-B_Mask.gbr, z80-cpu-mem-B_Silkscreen.gbr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]
2025-11-29 README: Update comments in BoM

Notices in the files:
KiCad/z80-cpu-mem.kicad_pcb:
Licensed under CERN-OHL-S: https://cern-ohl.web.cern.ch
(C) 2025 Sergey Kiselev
